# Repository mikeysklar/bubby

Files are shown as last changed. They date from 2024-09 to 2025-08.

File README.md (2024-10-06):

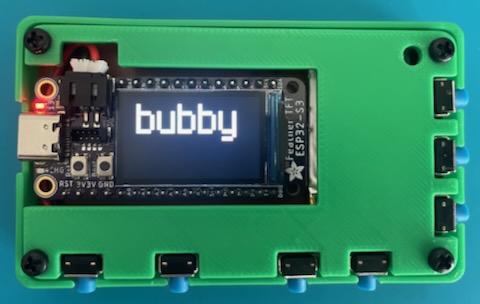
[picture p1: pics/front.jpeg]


BUBBY - A Pocket Chording Keyboard

It uses seven keys with chording patterns for input. The display makes for an excellent stand-alone training experience. It can be used as a USB HID keyboard or storage drive. This a sturdy every day carry design. Some frills, mostly function.

Features:
===

* Slim Form Factor 
    * thinner than a deck of cards in all dimensions
* 240x135 color LCD
    * view typed characters 
* Note Taking
    * save to flash
    * view as USB drive
* Timer
    * chord speed practice
* ESP32-S3 based
    * future BLE wireless HID option?
* CircuitPython 
    * based on [akmnos22 one handed chording keyboad](https://www.instructables.com/One-Handed-Chording-Keyboard/)
* Adafruit Feather Compatible
    * also works with Feather RP2040 (minus display code)
* USB-C 
    * computer/tablet/phone/pi HID interface
* Battery
    * 350mAh battery w/charger

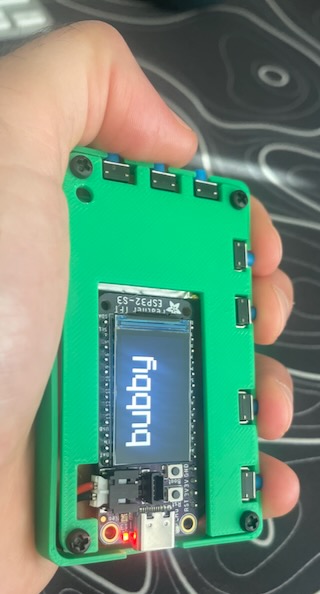
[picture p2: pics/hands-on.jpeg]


Enclosure
===

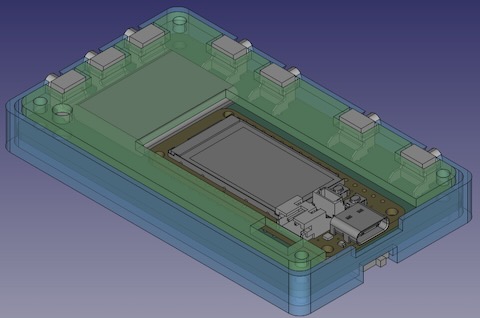
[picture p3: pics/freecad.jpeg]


* Designed in FreeCAD 0.21.2
* Printed on Bambu Lab P1P
* Dimensions (mm):
    * 80 x 46 x 12 
* Total Weight:
    * 40.6 grams

PCB design
===

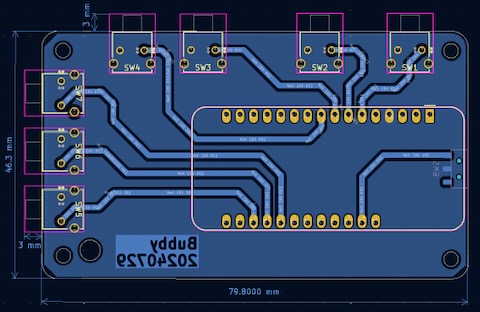
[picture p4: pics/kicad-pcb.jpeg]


* PCB files are KiCAD 8.x

Bill of Materials
===

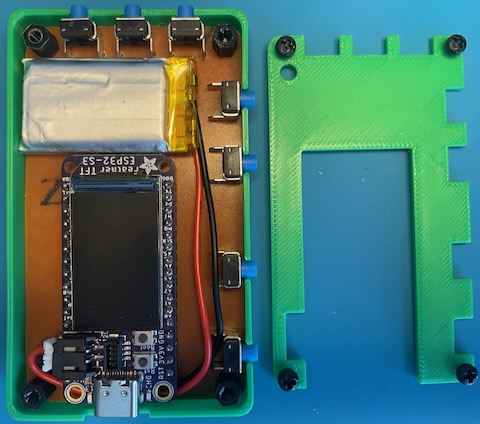
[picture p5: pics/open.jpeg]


| Item | Source | Part Number |
|:---:|:---:|:---:|
| Controller | Adafruit | [Feather ESP32-S3 TFT](https://www.adafruit.com/product/5483) |
| Bat 350mAh | Adafruit | [LiPo 3.7v ADA# 2750](https://www.adafruit.com/product/2750) |
| Buttons | Digi-Key | [450-1657-ND](450-1657-ND) |
| Pwr Switch | AliExpress | MSKT-12G03 |
| Screws | Adafruit | [M2.5 Machine Screws / Stand-off](https://www.adafruit.com/product/3299) |

Bottom
====

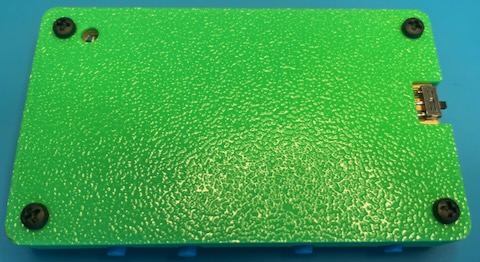
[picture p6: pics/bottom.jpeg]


* Slim power switch on bottom.
* Keychain hole option
    * works with smaller 150mAh battery

DIY PCB
===

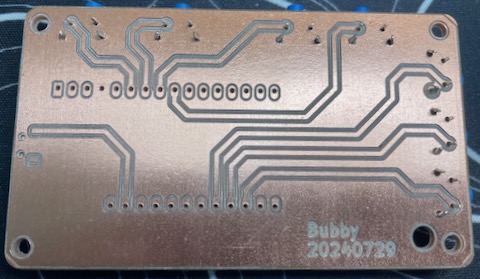
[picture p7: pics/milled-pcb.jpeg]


* Milled single sided on a Bantam Othermill.
    * traces PCB engraving bit 0.005 (mm)
    * drill holes 0.9 (mm)

Typing Speed
===



* monkeytype
* personal best :: 20 wpm 
    * @ 100% acc  
    * (left hand only)
* typical is 16 - 18 wpm
* limited by my own mental conversion of letters --> chords
* a realistic goal is 25+ wpm, per hand

Why Bubby
===

Bubby is an affectionate nickname for a friend, peer or even grandmother (Yiddish). This pocket keyboard acting as a digital everyday carry device. It is the friend that accompanies you.

Why Chording
===

The Human <--> Machine interface has enormous potential for improvement. The most egregious issue is the keyboard. The QWERTY layout is designed to be ineffecient. Now with VR, AR and wearables it makes sense to remix the earlier chording designs into new discrete interfaces.

Just Why?
===

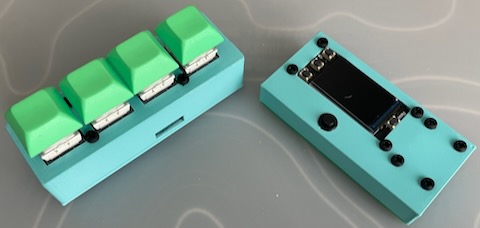
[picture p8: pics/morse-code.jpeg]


I hurt my knee. I had been running ultramarathons for ten years and needed surgery to clean things up. Immediately the twenty hours a week I had been putting into running were freed up. I read [Bruce Schneier's book "A Hacker's Mind"](https://www.amazon.com/Hackers-Mind-Powerful-Societys-Rules/dp/B0BP97G3NL) which describes a student reciting Pi to one hundred decimal places by using a phone vibrating morse code patterns. I was inspried and built a [BLE keyboard](https://github.com/mikeysklar/ble-morsecode-neokey) which used morse code communication. I slimmed it down into a Feather Rev TFT ESP32-S3 variation with vibrating motor and small built-in buttons. I realized that I like having a powered pocket keyboard / screen with some USB abilities. Also it would sure be nice to type faster.

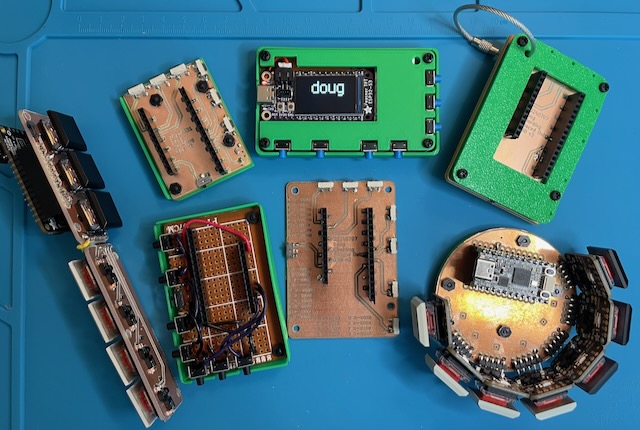
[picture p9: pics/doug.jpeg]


I made five variations of bubby. I call the series "doug" after Douglas Engelbart who popularized chording nearly 60 years ago. The first one I wired up with a protoboard actually turned out the most functional. I went back to that layout in the end. The other versions I tried going to had irritatingly small SMT buttons that were uncomfortable and would lift off the PCB from pressing too hard. Larger keys and PCBs like the stick and ring designs which use Kailh low profile Choc keys were too bulky and made a slight rattle. Sturdy and compact won out. 

Lessons Learned
===

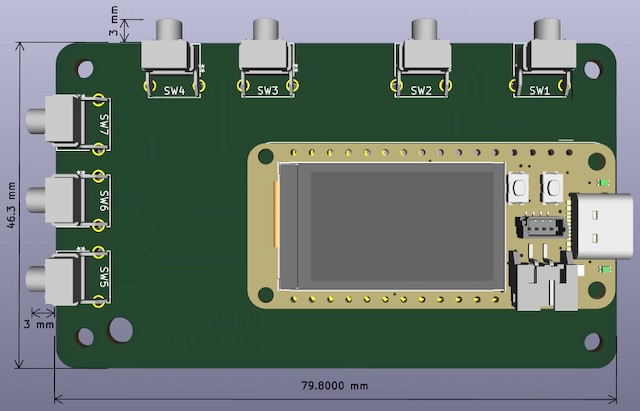
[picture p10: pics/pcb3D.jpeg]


* Memorizing Chords - Use muscle memory. Practice the patterns for single, double, triple and four digit combos. Then learn the lesser used keys with the thumb modifier. The more fingers that are pressing the less frequently the letter is typically used. Do not try to memorize with mnemonics, imagery or other memory tricks. I wasted a lot of time making elaborate charts and descriptions that were unnecessary. Getting faster with the chords has been the most rewarding part of the project. 

* Comfort - All enclosure edges need to be rounded. One straight edge becomes uncomfortable to hold and to carry in a pocket.

* Gloves - An unexpected, but welcome finding was that typing with gloves using real buttons was quite natural. 

* Power Switch - I ended up putting it right below the Feathers USB-C port on the bottom of the PCB. It is accesible and can be flicked on and off with one hand. It is not ideal in that the board needs to be spun around to flick the switch. I ran out of convenient locations so went with easy to place. 

* Button Click Noise - I wanted silent buttons. The blue right angle ones produce a slight click noise. Experimenting with Red Kailh buttons were silent when pressed, but had too many other issues for a pocket form factor. 

* BLE / WiFi - I'm using a board that works well with WiFi and is just now getting BLE HID support (not fully there with CircuitPython 9.2.x). My preference has been to not use any wireless. A stand alone device that does not require pairing has been a pleasure. I do plug it into USB-C to read my notes, charge the battery and practice on monkeytype. An Adafruit Feather RP2040 works well here with pin changes and display code commented out. I really like the display though.

* On the Go - Running or walking it is easy to take notes with this form factor. I do most of my practice going through the alphabet and chord patterns while walking the dog. 

* Fidget Toy - Another realization after a month of every day carry is that I have been using bubby as a fidget toy. It provides a calming flow state practicing the chords and letters.

Chords
===

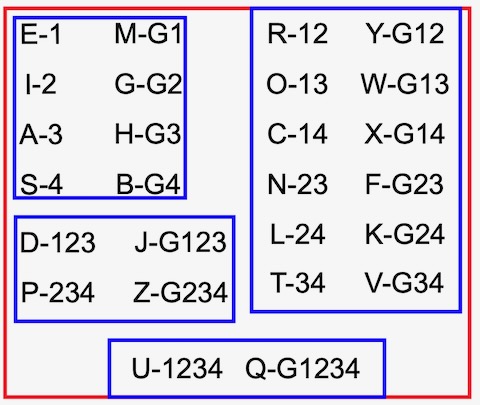
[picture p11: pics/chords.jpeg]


* Tested with CircuitPython 9.1.3
    * libraries:
        * adafruit_hid
        * adafruit_bitmap_font
        * adafruit_display_text
        * adafruit_ticks
    * code:
        cp bubby.py CIRCUITPY/code.py

* Chording ascii table, digits, punctuation, symbols and modifiers are all built-in. Firmware includes five additional custom modifiers shown in the table below.

| Key | Code |
|:---:|:---:|
| Backspace | 124 |
| Space | 134 |
| Clear | B-124 |
| USB | B-134 |
| Save | G-124 |
| xxx | G-134 |
| Timer | Y-124 |
| xxx | Y-134 |

| Symbol | Button Color | Description |
|---|---|---|
| **B** | Blue (inner/left thumb)  | White space / punctuation |
| **G** | Green (center thumb)| Alpha characters |
| **Y** | Yellow (outer/right thumb)| Numerics |

* akmnos22 has a [great chord reference chart in CSV format](docs/manualmap_chords.csv) this is the github table form of it.

| Key | Pinky | Ring | Middle | Index | Thumb |
|---|---|---|---|---|---|
| a | x | | | | |
| b | x | | | | g |
| c | x | | | x| |
| d | | x | x | x | |
| e | | | x | | |
| f | | x | x | | g |
| g | | | x | | g |
| h | | x | | | g |
| i | | | x | | |
| j | | x | x | x | g |
| k | x | | x | | g |
| l | x | | x | | |
| m | | | | x | g |
| n | | x | x | | |
| o | | x | | x | |
| p | x | x | x | | |
| q | x | x | x | x | g |
| r | | | x | x | |
| s | x | | | | |
| t | x | x | | | |
| u | x | x | x | x | |
| v | x | x | | | g |
| w | | x | | x | g |
| x | x | | | x | g |
| y | | | x | x | g |
| z | x | x | x | | g |
| Space | | | | . | b |
| Tab | | | . | | b |
| Shift | | | | | g |
| Alt | | | | | b |
| Control | | | | | y |
| Enter | | | . | . | b |
| ONE | | | | . | y |
| TWO | | | . | | y |
| THREE | | . | | | y |
| FOUR | . | | | | y |
| FIVE | | | . | . | y |
| SIX | | . | . | | y |
| SEVEN | . | . | | | y |
| EIGHT | | . | | . | y |
| NINE | . | | . | | y |
| ZERO | | . | . | . | y |
| period | | . | | | b |
| comma | | . | | . | b |
| forward_slash  | . | . | | | b |
| grave_accent | . | . | . | . | b |
| minus | . | | | | b |
| equals | | . | | . | b |
| left_bracket | . | | . | | b |
| right_bracket  | . | | | . | b |
| backslash | . | . | | | b |
| semicolon | . | . | | . | b |
| quote | . | | . | . | b |
| backspace | | . | . | | b |
| right_arrow | . | | . | . | y |
| left_arrow | . | . | | . | y |
| up_arrow | | | | . | y |
| down_arrow | . | | | . | y |
| escape | . | . | | | y |
| Home | . | | . | . | |
| End | . | . | | . | |
| Windows | . | . | | . | g |
| Delete | . | | . | . | g |

Schematic
===

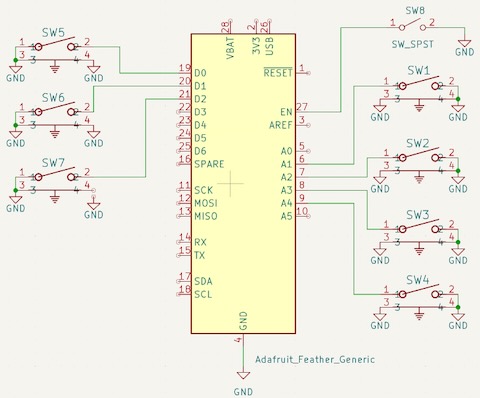
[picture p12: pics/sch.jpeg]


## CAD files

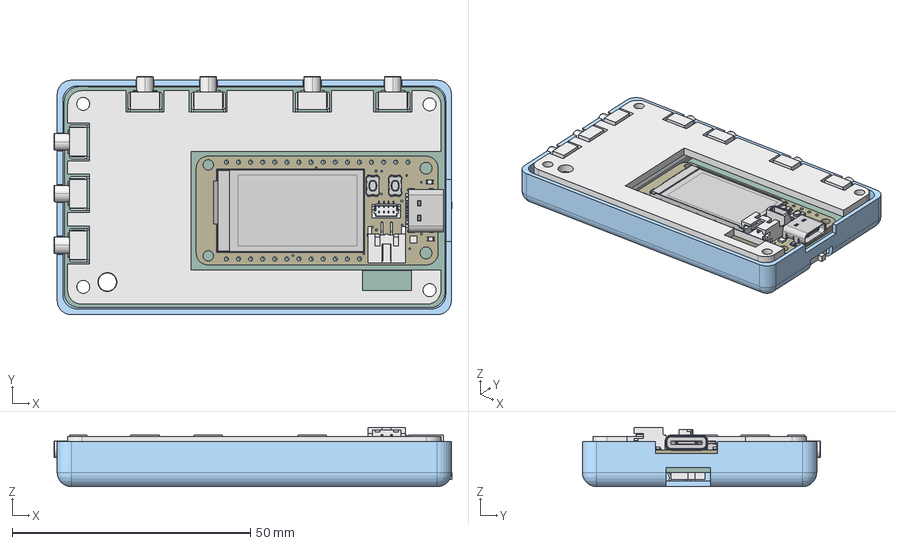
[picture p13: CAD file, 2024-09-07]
enclosure/bubby-case.FCStd
83.6 x 50.1 x 12.5 mm
C-1825027-8
C-1825027-009
C-1825027-010
C-1825027-011
C-1825027-012
C-1825027-013
C-1825027-014
Adafruit ESP32-S2 TFT Feather v3
Adafruit ESP32-S2 TFT Feather v004
Adafruit ESP32-S2 TFT Feather v005
Adafruit ESP32-S2 TFT Feather v006
Adafruit ESP32-S2 TFT Feather v007
Adafruit ESP32-S2 TFT Feather v008
Adafruit ESP32-S2 TFT Feather v009
Adafruit ESP32-S2 TFT Feather v010
Adafruit ESP32-S2 TFT Feather v011
Adafruit ESP32-S2 TFT Feather v012
Adafruit ESP32-S2 TFT Feather v013
Adafruit ESP32-S2 TFT Feather v014
Adafruit ESP32-S2 TFT Feather v015
Adafruit ESP32-S2 TFT Feather v016
Adafruit ESP32-S2 TFT Feather v017
Adafruit ESP32-S2 TFT Feather v018
Adafruit ESP32-S2 TFT Feather v019
Adafruit ESP32-S2 TFT Feather v020
Adafruit ESP32-S2 TFT Feather v021
Adafruit ESP32-S2 TFT Feather v022
Adafruit ESP32-S2 TFT Feather v023
Adafruit ESP32-S2 TFT Feather v024
Adafruit ESP32-S2 TFT Feather v025
Adafruit ESP32-S2 TFT Feather v026
Adafruit ESP32-S2 TFT Feather v027
Adafruit ESP32-S2 TFT Feather v028
Adafruit ESP32-S2 TFT Feather v029
Adafruit ESP32-S2 TFT Feather v030
Adafruit ESP32-S2 TFT Feather v031
Adafruit ESP32-S2 TFT Feather v032
Adafruit ESP32-S2 TFT Feather v033
Adafruit ESP32-S2 TFT Feather v034
Adafruit ESP32-S2 TFT Feather v035
Adafruit ESP32-S2 TFT Feather v036
Adafruit ESP32-S2 TFT Feather v037
Adafruit ESP32-S2 TFT Feather v038
Adafruit ESP32-S2 TFT Feather v039
Adafruit ESP32-S2 TFT Feather v040
Adafruit ESP32-S2 TFT Feather v041
Adafruit ESP32-S2 TFT Feather v042
Adafruit ESP32-S2 TFT Feather v043
Adafruit ESP32-S2 TFT Feather v044
Adafruit ESP32-S2 TFT Feather v045
Adafruit ESP32-S2 TFT Feather v046
Adafruit ESP32-S2 TFT Feather v047
Adafruit ESP32-S2 TFT Feather v048
Adafruit ESP32-S2 TFT Feather v049
Adafruit ESP32-S2 TFT Feather v050
Adafruit ESP32-S2 TFT Feather v051
Adafruit ESP32-S2 TFT Feather v052
Adafruit ESP32-S2 TFT Feather v053
Adafruit ESP32-S2 TFT Feather v054
Adafruit ESP32-S2 TFT Feather v055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

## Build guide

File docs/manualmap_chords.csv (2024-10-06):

Key | Pinky | Ring | Middle | Index | Thumb (blue, green, yellow, left-to-right) | Notes
a| | x
b|x
c|x |  | x
d| | xxx
e| |  |  | .
f| | xx | | | g
g| |  | x | | | g
h| | x |  | | | g
i| |  | x
j| | xxx| | g
k|x | x | | | g
l|x | x
m| |  |  | x| | g
n| | xx
o| | x | x
p|xxx
q|xxxx| | g
r| |  | xx
s|x
t|xx
u|xxxx
v|xx |  | | | g
w| | x | x| | g
x|x |  | x| | g
y| |  | xx| | g
z|xxx | | | g
Space| |  |  | . | b
Tab| |  | . |  | b
Shift| |  |  |  | g | Is a modifier key
Alt| |  |  |  | b | Is a modifier key
Control| |  |  |  | y | Is a modifier key
Enter| |  | . | . | b
ONE| |  |  | . | y
TWO| |  | . |  | y
THREE| | . |  |  | y
FOUR|. |  |  |  | y
FIVE| |  | . | . | y
SIX| | . | . |  | y
SEVEN|. | . |  |  | y
EIGHT| | . |  | . | y
NINE|. |  | . |  | y
ZERO| | . | . | . | y
period| | . |  |  | b
comma| | . |  | . | b
forward_slash|. | . |  |  | b
grave_accent|. | . | . | . | b
minus|. |  |  |  | b
equals| | . | . | . | b
left_bracket|. |  | . |  | b
right_bracket|. |  |  | . | b
backslash|. | . | . |  | b
semicolon|. | . |  | . | b
quote|. |  | . | . | b
backspace| | . | . |  | b
right_arrow|. |  | . | . | y
left_arrow|. | . |  | . | y
up_arrow|. |  |  | . | y
down_arrow|. | . | . | . | y
escape|. | . | . |  | y
Home|. |  | . | . |  | Is a modifier key
End|. | . |  | .
Windows|. | . |  | . | g
Delete|. |  | . | . | g

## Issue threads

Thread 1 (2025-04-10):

shift, ctl, alt?

catfoobar, 2025-04-10:
Great project.

Context, C coder fumbling with python : )  Was wondering what the intention was for the single shift, ctl and alt buttons.  Assumed it would work as a 'normal' keyboard, but was surprised to find pressing any of them by themselves cause the code to break.  A NameError (below, pressed 'i', then 'l_shift') :

```
Change in state detected on pin board.A3 to off (last value was on )
Change in state detected on pin board.A3 to on (last value was off )
current_key_comb (False, False, True, False, False, False, False)
Sending text: 12
Change in state detected on pin board.D5 to off (last value was on )
Change in state detected on pin board.D5 to on (last value was off )
current_key_comb (False, False, False, False, True, False, False)
Sending text: 226
Traceback (most recent call last):
  File "code.py", line 401, in <module>
  File "code.py", line 370, in update
  File "code.py", line 383, in onstatechange
  File "code.py", line 297, in send_chord
NameError: local variable referenced before assignment

Code done running.

Adafruit CircuitPython 9.2.7 on 2025-04-01; Adafruit Feather ESP32-S3 TFT with ESP32S3
>>> [A
```

Without thinking too hard about the code, I put a key_buf = '' (null) above the offending line, which avoids the crash, but still seems to not do anything expected.  Yes.  I still do need to decompose the code to understand it better.  Was wondering if there is any more documentation somewhere that might help?

Also, noted some commented out code ( kb = Keyboard(usb_hid.devices near the front, and three instances of calls to send_kb_report()).  Were these simply to disable keyboard function via USB?  So the device just remains in portable/practice mode?

Again, great project.  And congrats for winning the contest.  I really believe chorded keyboards are going to be big deal (eventually) - it's a perfect application for wearing display glasses, which are getting better and better to code on.  Being able to use a portable pocket keyboard to touch type is why I duplicated your project.  I have prescription lenses inside the glasses and touch type with a normal keyboard on my lap.  But I don't want to drag a normal keyboard around with me all the time.  This is perfect.  Would be happy to contribute once I understand more about what's going on : )

catfoobar, 2025-04-10:
Update, looks like key_buf needed to be declared as global in send_chord, which I included in the code.  It doesn't crash now.  But the question still remains regarding the function of the shift/ctl/alt keys.  I was sort of expecting shift to be a modifier that would then be applied to the next (or next several) characters coming down the pipe.  Like, <shift> 'a' would result in a 'A' being sent.

mikeysklar, 2025-04-10:
I like your thinking. The transition from monitors to glasses is coming fast. I've actually designed several more chorded keyboards and made some changes to lower latency. The goal being 300 wpm with two handed chording.

I've not worked out the ctrl / gui / alt / shift. I'm leaning towards layers to make a clearer chord table. The current code doesn't lock and send the modifier correctly. PRs are welcome.

This is my latest hardware I've been working with called [c7k (Chording 7 Key)](https://github.com/mikeysklar/c7k) which has a much faster response time and is I2C based. I wanted to decouple from a specific controller for easier BLE, WiFi or just direct USB-C access. I'm working towards a c7k standard this month. It is inspired by how well [ARTSEY has arranged their layout](url), but unfortunately that format is not conducive to mobile use.

catfoobar, 2025-04-11:
c7k looks good - great to decouple using i2c.  Love the ambition of 300 wpm.

Was thinking, depending on how my experience goes with adapting to chords, once the python code is functioning well enough, I'd probably want to retool the entire thing in asm/C.  That would give new meaning to 'snappy'.  My (long) career is embedded SW, so, I'm using python like a weird sandbox.  This kind of abstraction is really uncomfortable for me.  It blows my mind we've gotten to a point where running an interpreted language on a nominally embedded micro is a thing.  I do absolutely recognize it lets you play really quickly - it just seems really really heavy for such a fairly simple task.  This all could be done on a 25 cent PIC.  Pardon, my engineer is showing...

That said, I'll continue improving my python and intend to chip away at helping make the modifier keys do what they do on a 'normal' keyboard.  It'll slow things down a bit since they'll have to be serially entered, but I'd really like access to as many key codes as possible to make it functional for running things like vim.  I love coding and want be able to do it untethered.  Also interested in eventually combining right and left hands.  But now one is good, preferable really  - I still need the other hand to steer the bike : )

In parallel, I'm thinking of 3d printing some ideas for packaging mods - although Bubby is a miracle of compact beauty, it doesn't fit my hand very well.  I actually went down to the local craft shop and got some clay to play with.  I molded it into different shapes and stuck the buttons in where they felt more natural.  It's been a fun diversion.  Sounds like you've been doing similar things.

mikeysklar, 2025-04-11:
You have a lot of good ideas.

If you would like to help with putting together a chording 7 key standard interface I think that would help others. The SAIE layout used here prioritizes the the high frequency keys to minimal key presses.

eg. 'a' takes one key and 'z' requires four.

Sadly, there is nothing in terms of key locks and layers documented so that is all missing.

I agree that a low cost controller can achieve all this. I've been offloading to the MCP23008 for I2C and watching for buttons. It relieves the main controller from having to loop around and the interface is already faster than my daily driver qwerty over BLE.

It will be interesting to see what you come up with ergonomics. My experience has been that something to press against, grip or help balance is necessary. Chords are hard to enter if there is any slip in the grip.

I'm a VIM user also so we share the same goal to code untethered.

Find me on signal. @mikeysklar.66

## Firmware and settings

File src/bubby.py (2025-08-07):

import board
import displayio
import terminalio
import digitalio as dio
import microcontroller as mc
import time
import supervisor
import usb_hid
import storage
from adafruit_hid.keyboard import Keyboard
from adafruit_hid.keycode import Keycode
from adafruit_display_text import label

# kb = Keyboard(usb_hid.devices)
usbmode = False
CAN_CHORD = True

filename = "/notes.txt"
word_buf = ''
key_buf = ''
time_buf = ''
map_char = ''
last_detected_time = None
usbmode = False

# Display setup
display = board.DISPLAY
main_group = displayio.Group()
display.root_group = main_group

# String label
word_label = label.Label(font=terminalio.FONT)
word_label.text = word_buf
word_label.scale = 3
word_label.anchor_point = (1, 0)
word_label.anchored_position = (display.width, 0)

# Last key label
mcode_label = label.Label(font=terminalio.FONT)
mcode_label.text = key_buf
mcode_label.scale = 3
mcode_label.anchor_point = (1, 1)
mcode_label.anchored_position = (display.width, display.height)

# Timer label
time_label = label.Label(font=terminalio.FONT)
time_label.text = time_buf
time_label.scale = 3
time_label.anchor_point = (0, 1)
time_label.anchored_position = (0, display.height)

# Add labels to display
main_group.append(word_label)
main_group.append(time_label)

DEBOUNCE_DURATION = 30_000_000

CONFIG_INPUT_PINS = [
    mc.pin.GPIO17,  # Pinky
    mc.pin.GPIO16,  # Ring
    mc.pin.GPIO15,  # Middle
    mc.pin.GPIO14,  # Index
    mc.pin.GPIO5,   # Left thumb
    mc.pin.GPIO6,   # Middle thumb
    mc.pin.GPIO9,   # Right thumb
]

KEYS = []

# For scrolling notes.txt
line_index = 0
notes = []

def load_notes():
    try:
        with open(filename, "r") as file:
            return file.readlines()
    except OSError:
        return ["No notes available."]

notes = load_notes()

def wrap_text(text, max_chars_per_line):
    wrapped = []
    while len(text) > 0:
        wrapped.append(text[:max_chars_per_line])
        text = text[max_chars_per_line:]
    return wrapped

def update_display_scroll():
    global word_buf
    global line_index
    global word_label

    max_chars_per_line = 13  # Adjust if needed

    if line_index >= len(notes):
        line_index = 0
    elif line_index < 0:
        line_index = len(notes) - 1

    line_text = f"{line_index + 1}: {notes[line_index].strip()}"

    wrapped_lines = wrap_text(line_text, max_chars_per_line)

    word_buf = "\n".join(wrapped_lines[:3])

    word_label.scale = 3
    word_label.text = word_buf

hid_keycode_to_char = {
    4: 'a', 5: 'b', 6: 'c', 7: 'd', 8: 'e', 9: 'f', 10: 'g',
    11: 'h', 12: 'i', 13: 'j', 14: 'k', 15: 'l', 16: 'm', 17: 'n',
    18: 'o', 19: 'p', 20: 'q', 21: 'r', 22: 's', 23: 't',
    24: 'u', 25: 'v', 26: 'w', 27: 'x', 28: 'y', 29: 'z',
    30: '1', 31: '2', 32: '3', 33: '4', 34: '5',
    35: '6', 36: '7', 37: '8', 38: '9', 39: '0',
    40: '\n', 41: 'esc', 42: 'backspace', 43: 'tab', 44: ' ',
    45: '-', 46: '=', 47: '[', 48: ']', 49: '\\',
    51: ';', 52: "'", 53: '`', 54: ',', 55: '.', 56: '/',
    58: 'F1', 59: 'F2', 60: 'F3', 61: 'F4', 62: 'F5', 63: 'F6',
    64: 'F7', 65: 'F8', 66: 'F9', 67: 'F10', 68: 'F11', 69: 'F12',
    70: 'print_screen', 71: 'scroll_lock', 72: 'pause', 73: 'insert',
    74: 'home', 75: 'page_up', 76: 'delete', 77: 'end', 78: 'page_down',
    79: 'right_arrow', 80: 'left_arrow', 81: 'down_arrow', 82: 'up_arrow',
}

def get_char_from_hid_keycode(keycode):
    return hid_keycode_to_char.get(keycode, "Unknown")

# (CHORD_TABLE omitted for brevity—include your full mapping)
CHORD_TABLE = {
    (False, False, False, True, False, False, False): Keycode.E,
    (False, False, True, False, False, False, False): Keycode.I,
    (False, True, False, False, False, False, False): Keycode.A,
    (True, False, False, False, False, False, False): Keycode.S,
    (False, False, True, True, False, False, False): Keycode.R,
    (False, True, True, False, False, False, False): Keycode.N,
    (True, True, False, False, False, False, False): Keycode.T,
    (False, True, False, True, False, False, False): Keycode.O,
    (True, False, True, False, False, False, False): Keycode.L,
    (True, False, False, True, False, False, False): Keycode.C,
    (False, True, True, True, False, False, False): Keycode.D,
    (True, True, True, False, False, False, False): Keycode.P,
    (True, True, True, True, False, False, False): Keycode.U,
    (False, False, False, True, False, True, False): Keycode.M,
    (False, False, True, False, False, True, False): Keycode.G,
    (False, True, False, False, False, True, False): Keycode.H,
    (True, False, False, False, False, True, False): Keycode.B,
    (False, False, True, True, False, True, False): Keycode.Y,
    (False, True, True, False, False, True, False): Keycode.F,
    (True, True, False, False, False, True, False): Keycode.V,
    (False, True, False, True, False, True, False): Keycode.W,
    (True, False, True, False, False, True, False): Keycode.K,
    (True, False, False, True, False, True, False): Keycode.X,
    (False, True, True, True, False, True, False): Keycode.J,
    (True, True, True, False, False, True, False): Keycode.Z,
    (True, True, True, True, False, True, False): Keycode.Q,
    (False, False, False, True, True, False, False): Keycode.SPACE,
    (False, False, True, False, True, False, False): Keycode.TAB,
    (False, False, False, False, False, True, False): Keycode.SHIFT,
    (False, False, False, False, True, False, False): Keycode.ALT,
    (False, False, False, False, False, False, True): Keycode.CONTROL,
    (False, False, True, True, True, False, False): Keycode.ENTER,
    (False, False, False, True, False, False, True): Keycode.ONE,
    (False, False, True, False, False, False, True): Keycode.TWO,
    (False, True, False, False, False, False, True): Keycode.THREE,
    (True, False, False, False, False, False, True): Keycode.FOUR,
    (False, False, True, True, False, False, True): Keycode.FIVE,
    (False, True, True, False, False, False, True): Keycode.SIX,
    (True, True, False, False, False, False, True): Keycode.SEVEN,
    (False, True, False, True, False, False, True): Keycode.EIGHT,
    (True, False, True, False, False, False, True): Keycode.NINE,
    (False, True, True, True, False, False, True): Keycode.ZERO,
    (False, True, False, False, True, False, False): Keycode.PERIOD,
    (False, True, False, True, True, False, False): Keycode.COMMA,
    (True, True, False, False, True, False, False): Keycode.FORWARD_SLASH,
    (True, True, True, True, True, False, False): Keycode.GRAVE_ACCENT,
    (True, False, False, False, True, False, False): Keycode.MINUS,
    (False, True, True, True, True, False, False): Keycode.EQUALS,
    (True, False, True, False, True, False, False): Keycode.LEFT_BRACKET,
    (True, False, False, True, True, False, False): Keycode.RIGHT_BRACKET,
    (True, True, True, False, True, False, False): Keycode.BACKSLASH,
    (True, True, False, True, True, False, False): Keycode.SEMICOLON,
    (True, False, True, True, True, False, False): Keycode.QUOTE,
    (True, False, True, True, False, False, True): Keycode.RIGHT_ARROW,
    (True, True, False, True, False, False, True): Keycode.LEFT_ARROW,
    (True, False, False, True, False, False, True): Keycode.UP_ARROW,
    (True, True, True, True, False, False, True): Keycode.DOWN_ARROW,
    (True, True, True, False, False, False, True): Keycode.ESCAPE,
    (True, False, True, True, False, False, False): Keycode.HOME,
    (True, True, False, True, False, False, False): Keycode.END,
    (True, True, False, True, False, True, False): Keycode.WINDOWS,
    (True, False, True, True, False, True, False): Keycode.DELETE,
    (True, False, True, True, False, False, True): Keycode.F1,
    (True, False, True, True, False, True, False): Keycode.F2,
    (True, False, True, True, True, False, False): Keycode.F3,
    (True, True, False, True, False, True, False): Keycode.F4,
    (True, False, True, True, False, False, False): Keycode.BACKSPACE,
    (True, True, False, True, False, False, False): Keycode.SPACE,
}


current_modifiers = 0
sticky_modifiers = 0
last_modifier = 0
start_time = time.monotonic_ns()
last_modifier_time = time.monotonic_ns()

def prime_chord():
    global CAN_CHORD
    CAN_CHORD = True

def send_chord():
    global CAN_CHORD
    global last_modifier, last_modifier_time
    global current_modifiers, sticky_modifiers
    global word_buf, key_buf, map_char
    global last_detected_time, time_buf
    global usbmode
    global line_index

    if not CAN_CHORD:
        return

    current_key_comb = tuple(not key.lastvalue for key in KEYS)

    try:
        key_to_send = CHORD_TABLE[current_key_comb]
        map_char = key_to_send
    except KeyError:
        return

    CAN_CHORD = False

    # Handle scrolling first
    if map_char == Keycode.UP_ARROW:
        line_index -= 1
        update_display_scroll()
        return
    elif map_char == Keycode.DOWN_ARROW:
        line_index += 1
        update_display_scroll()
        return

    # Default processing
    if map_char < 57:
        key_buf = get_char_from_hid_keycode(map_char)

    # ---- Key actions ----
    if map_char == Keycode.BACKSPACE:  # 42
        if len(word_buf) > 0:
            word_buf = word_buf[:-1]
        key_buf = ''

    elif map_char == 58:  # start timer
        last_detected_time = time.monotonic()
        key_buf = ''

    elif map_char == 59:  # save file
        storage.remount("/", False)
        with open(filename, "a") as file:
            file.write(f"{word_buf},{time_buf}\n")
        word_buf = ''
        key_buf = ''

    elif map_char == 60:  # clear
        last_detected_time = None
        word_buf = ''
        key_buf = ''
        time_buf = ''

    elif map_char == 61:  # USB mode
        kb = Keyboard(usb_hid.devices)
        last_detected_time = None
        usbmode = True
        word_buf = ''
        key_buf = ''
        time_buf = ''

    else:
        # printable / everything else
        key_buf = get_char_from_hid_keycode(map_char)
        word_buf += key_buf

    if last_detected_time is not None and last_detected_time > 0:
        elapsed_time = int(time.monotonic() - last_detected_time)
        time_buf = f"{elapsed_time}"
        time_label.text = time_buf

    word_label.scale = 3
    word_label.text = str(word_buf)
    time_label.text = str(time_buf)

class Key:
    def __init__(self, cpin):
        self.cpin = cpin
        pin = dio.DigitalInOut(cpin)
        pin.direction = dio.Direction.INPUT
        pin.pull = dio.Pull.UP
        self.pin = pin
        self.lastvalue = pin.value
        self.value = self.lastvalue
        self.lastchange = time.monotonic_ns()

    def update(self):
        self.value = self.pin.value
        if self.value != self.lastvalue:
            tnow = time.monotonic_ns()
            if tnow < self.lastchange + DEBOUNCE_DURATION:
                return False
            self.lastchange = tnow
            self.onstatechange()
            self.lastvalue = self.value
            return True
        return False

    def onstatechange(self):
        if self.value:
            send_chord()
        else:
            prime_chord()

for cpin in CONFIG_INPUT_PINS:
    KEYS.append(Key(cpin))

led = dio.DigitalInOut(board.LED)
led.direction = dio.Direction.OUTPUT

while True:
    led.value = KEYS[0].pin.value
    for key in KEYS:
        key.update()

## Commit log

2024-09-01 Initial Files
    Completed project. Post after a month of testing and refinement.
    [bubby-case-bot.stl, bubby-case-top.stl, bubby-case.FCStd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]
2024-09-07 minor updates
    filet case bottom edge and more frequent keyboard macros
    [bubby-case-bot.stl, bubby-case.FCStd]
2024-09-08 chords
    csv chart
    [manualmap_chords.csv]
2024-09-09 updates
    * esp32-s3 bootloader 0.20.1
    * circuitpython 9.1.3
    * libraries
    * fixed bubby.py bug with unassigned chords crashing.
    [bubby.py]
2024-09-10 reformat landing
    moved schematic to bottom
2024-09-10 3d pcb render
2024-09-18 usb mode change
    usb toggle was causing a crash when not plugged in, switched off the main green thumb key to blue (white space) thumb to avoid accidental contacts in stand-alone mode.
    [bubby.py]
2024-10-06 ascii chars fix
    code was fine, but docs was off
    [manualmap_chords.csv]
2025-07-23 fixed scroll back font
    [bubby.py]
